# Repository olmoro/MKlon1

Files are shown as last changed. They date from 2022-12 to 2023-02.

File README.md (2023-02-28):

# <p align="center">MKlon1
# <p align="center">Вариант ЗУ с блоком управления на ESP32
## <p align="center">Модульное зарядное устройство на ESP-WROOM-32D
## <p align="center">проект Arduino.
#### <p align="right">редакция от 1 марта 2023 года 
#### <p align="right">Подключение ЖК-дисплея 3.5" 

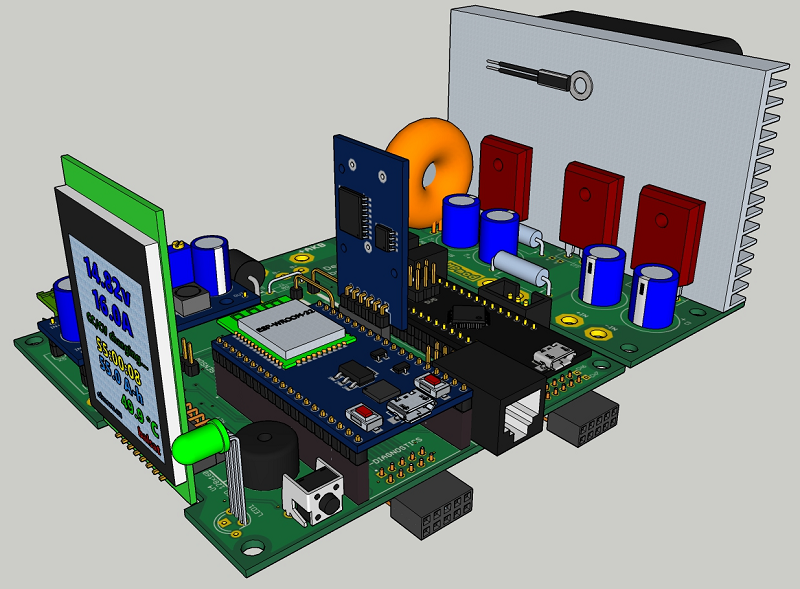
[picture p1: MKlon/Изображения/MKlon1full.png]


### MKlon1 - это вариант ЗУ, в котором блок управления и силовой  блок выполнены на отдельных платах. Что это дает?

Во-первых, блок управления - весьма универсальное устройство, применение которого не ограничивается зарядным устройством, чего не скажешь о силовом блоке, тем более, что силовой блок может "масштабироваться" - сегодня достаточно 6 ампер, а завтра ...

Во-вторых, платы имеют максимальный размер не более 102 мм, что позволяет заказывать их на [JLCPCB](https://jlcpcb.com/) по символической цене.

И, наконец, в случае неприятностей с силовым блоком более дорогой блок управления пострадает в меньшей степени.

Не стесняйтесь использовать код и технические решения в качестве отправной точки для вашего собственного проекта!

### <p align="center">Особенности реализации блока управления.

1. Модульность
  - Модуль [ESP32-DevKitC V4 38pin](https://aliexpress.ru/item/4000090521976.html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). Можно, конечно, ограничиться другими версиями ESP32-DevKit с уже распаяным ESP-WROOM-32D, но перспективнее будет запаять ESP32 с 16МБ памяти самостоятельно вместо обычных 4МБ. Выбор 38pin варианта ESP32-DevKitC вместо 30pin показался более подходящим при разработке топологии платы блока управления, не более того.
  - Модуль [SAMD21 M0-Mini](https://aliexpress.ru/item/4000169610268.html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). 
  - [Модуль прецизионных часов DS3231 IIC](https://aliexpress.ru/item/32822420722.html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). Опциональная позиция.
  - [Понижающий модуль LM2596](https://aliexpress.ru/item/32464248769.html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).
  - [Полноцветный ЖК-дисплей 1,8 дюйма 1,8x128 SPI TFT 160*128, модуль ST7735S](https://aliexpress.ru/item/1005003768467259.html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)
  - Или [ЖК-модуль HD 3,5 дюйма SPI, 480*320, TFT-модуль ILI9486 ILI9488, сенсорная панель, 65K цветов](https://sl.aliexpress.ru/p?key=ypWZtdN).  
  - [MIKROE-1892, I2C 1-Wire click DS2482-800 Development Kit for MikroBUS MIKROE-1892](https://www.chipdip.ru/product/mikroe-1892?ysclid=lc5odv6n7p797564389) может использоваться в вашем проекте для подключения до 8 датчиков температуры, но в этом проекте по конструктивным соображениям выбран вариант на DS2482-100 с сетевым подключением датчиков DS18B20 к единственному разъему на несущей плате.
2. Разъемы для установки модулей рекомендую не ставить те, что идут в комплекте, а использовать цанговые [разъемы](https://www.chipdip.ru/product0/8002610753), где это возможно.

3. Подключение модуля дисплея. Посадочное место на плате имеет два ряда по 8 контактов. Можно установить 8-контактный разъем для 1,8 дюймового дисплея или 14-контактный для 3,5-дюймового. В этом случае не устанавливаются RGB-светодиод и зуммер, так как портов ESP32 как бы много их не казалось, на всё не хватает.

4. Выходное напряжение модуля питания следует установить на 5,5 вольта. Потенциометр желательно заменить на подобранный резистор от греха подальше.

5. Два узла схемы нуждаются в гальванически развязанных [источниках питания](https://aliexpress.ru/item/1005003568781579.html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) на 5 и 12 вольт мощностью 1 ватт.

5. Токовые шунты могут устанавливаться как проволочные, так и металлопленочные SMD из расчета падения напряжения на шунте не более 200 милливольт при максимальном токе разряда (да и заряда тоже). 

6. Разъемы диагностики сигналов интерфейсов UART, SPI, IIC выведены на боковую сторону (если смотреть со стороны дисплея) двумя разъемами для подключения [логического анализатора](https://aliexpress.ru/item/1005004783286574.html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). На разъемы желательно нанести маркировку для правильного подключения логического анализатора. Впрочем, ему ничего не сделается при неправильном подключении.

7. Клавиатура пятикнопочная, подключается на разъем [6pin](https://aliexpress.ru/item/1005001530994945.html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). Резистивный делитель обеспечивает оптимальное напряжение на аналоговом входе микроконтроллера при нажатии одной кнопки. Подключение энкодера не предусмотрено.

8. Четырехточечное подключение к аккумуляторной батарее позволяет измерять напряжение на клеммах от -2 до 20 вольт и ток обоих направлений на одном шунте по дифференциальной схеме. Не любые ["крокодилы"](https://aliexpress.ru/item/4000593884517.html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) подойдут для этой цели, а только такие, с изолированными друг от друга "щечками". Для силовых проводов подойдет [12AWG](https://aliexpress.ru/item/32760772505.html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), для сигнальных - [26AWG](https://aliexpress.ru/item/32822800017.html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), скрепленных попарно термоусадкой c разумной дистанцией.

9. Охлаждение [радиатора](https://aliexpress.ru/item/1005003036398261.html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производится) 12-вольтовым вентилятором, напряжение должно регулироваться ШИМ. 

10. Мониторинг питания в пределах +20 вольт имеется.

11. Интерфейсы USB обоих процессорных модулей доступны без отключения модулей от несущей платы. Следует учесть, что у них разные "земли", и одновременное подключение к компьютеру не желательно, однако и не приводит к каким-либо печальным последствиям, разве что немного "уплывают" калибровки.

12. Кнопка сброса подключена к обоим процессорным модулям.

13. "Хитрый" 6-pin разъем с закороченными контактами в линии связи управляющего модуля ESP32 с измерительным SAMD21 по асинхронному интерфейсу можно не устанавливать. Однако если возникает необходимость по отдельности управлять каждым модулем в процессе разработки, то он понадобится, а проводники перерезать. Потом использовать джамперы.

14. На силовом модуле размещена лишь символическая нагрузка цепи разряда, необходимая для поддержания устойчивой работы преобразователя в некоторых режимах. Для разряда током заявленной величины клеммы "LOAD" должны быть закорочены или к ним подключена внешняя нагрузка в разумных пределах.

15. Код предлагается портировать из проектов MKlon2 и MDrv2 самостоятельно.

16. Если вы думаете, что я что-то пропустил или что-то не так, пожалуйста, дайте мне знать: molvas66 на mail.ru

17. И, наконец, видео без звука и титров [95M скачать](https://github.com/olmoro/MKlon1/blob/main/MKlon/%D0%92%D0%B8%D0%B4%D0%B5%D0%BE/MKlon1.mp4?raw=true)

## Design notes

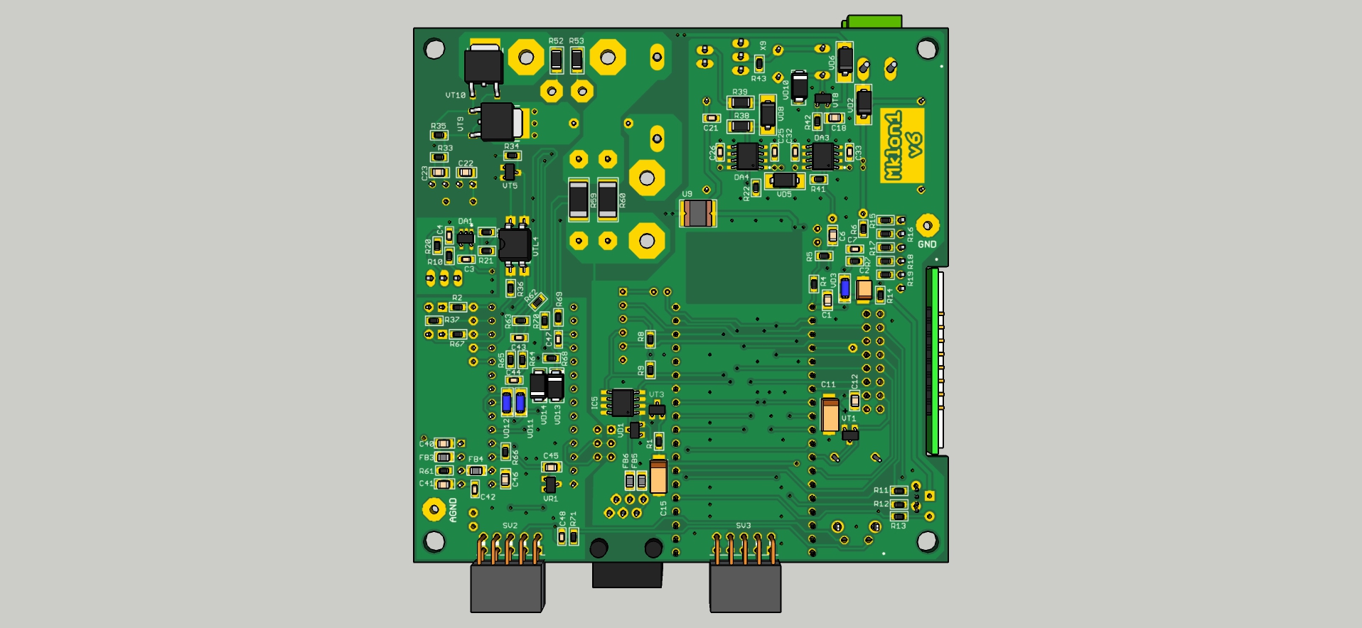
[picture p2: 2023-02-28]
Модуль управления/Изображения/MKlon1v6_bot.jpg

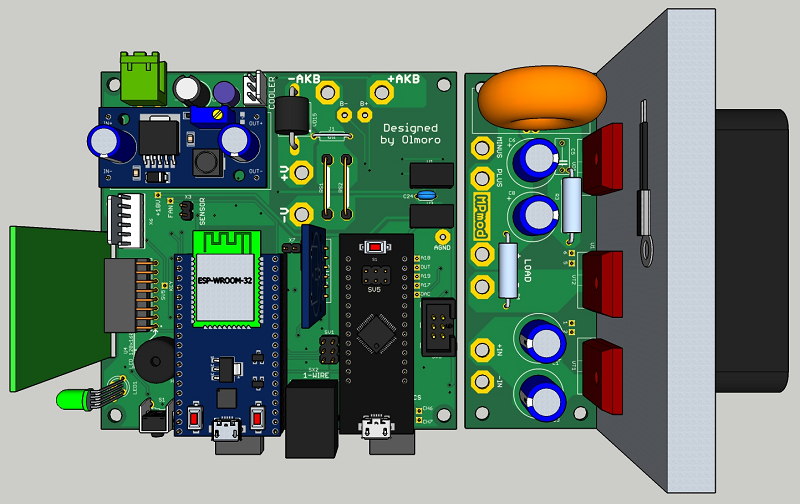
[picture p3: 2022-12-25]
MKlon/Изображения/MKlon1full_top.png

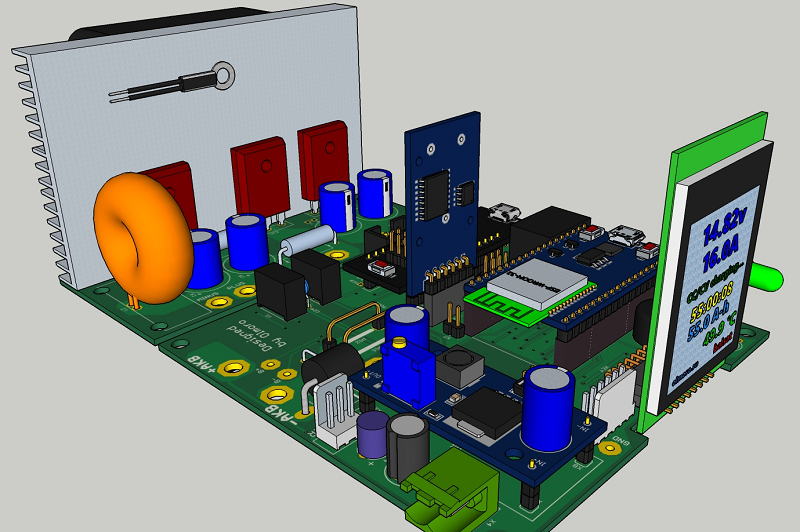
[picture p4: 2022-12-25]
MKlon/Изображения/MKlon1full2.png

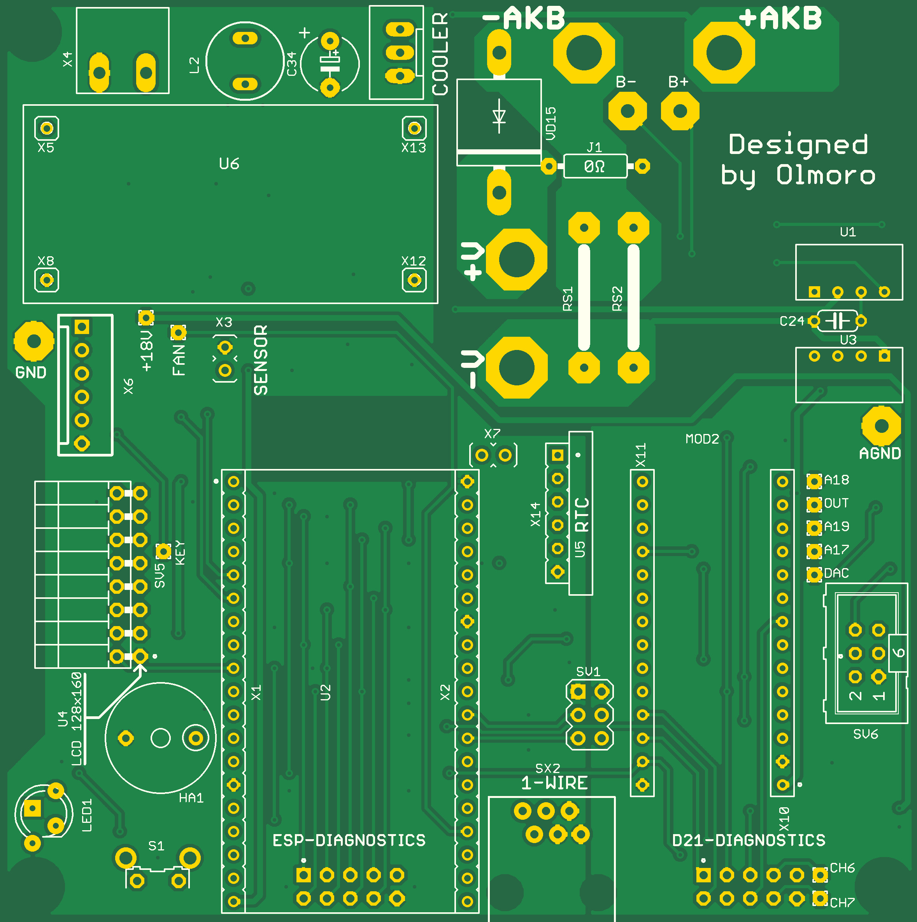
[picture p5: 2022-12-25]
Модуль управления/Изображения/eagleUp_Mklon1v3_board_top.jpg

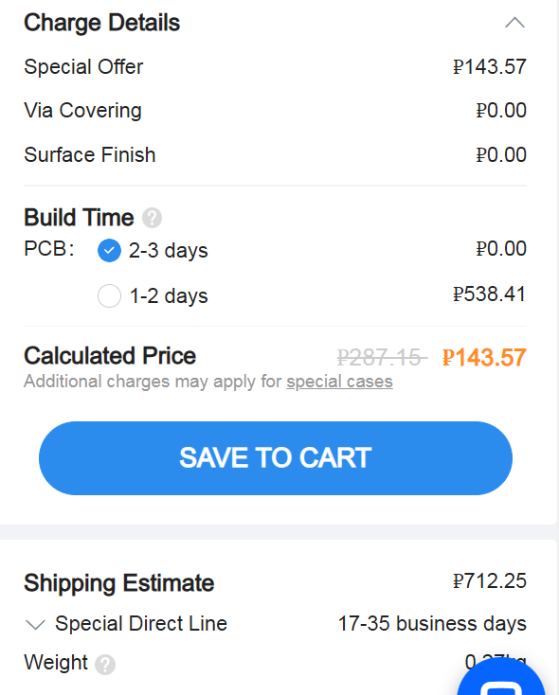
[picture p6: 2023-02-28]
Модуль управления/Gerber/price.png

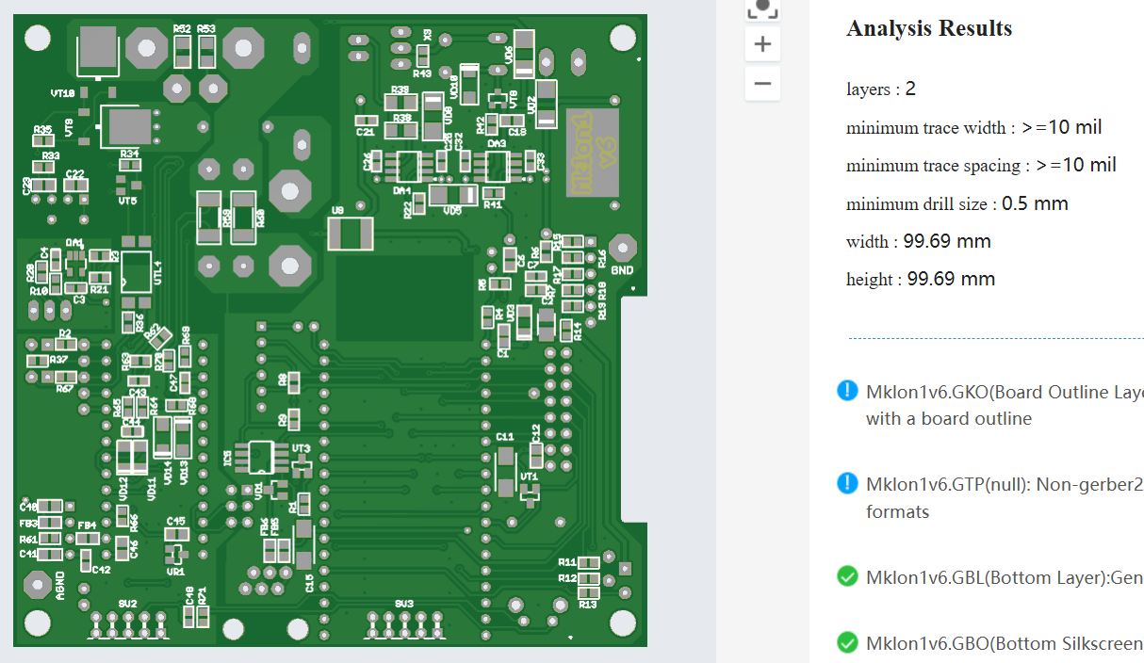
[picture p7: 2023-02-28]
Модуль управления/Gerber/bottom.png

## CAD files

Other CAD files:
Силовой модуль/Модели/MPmod.skp

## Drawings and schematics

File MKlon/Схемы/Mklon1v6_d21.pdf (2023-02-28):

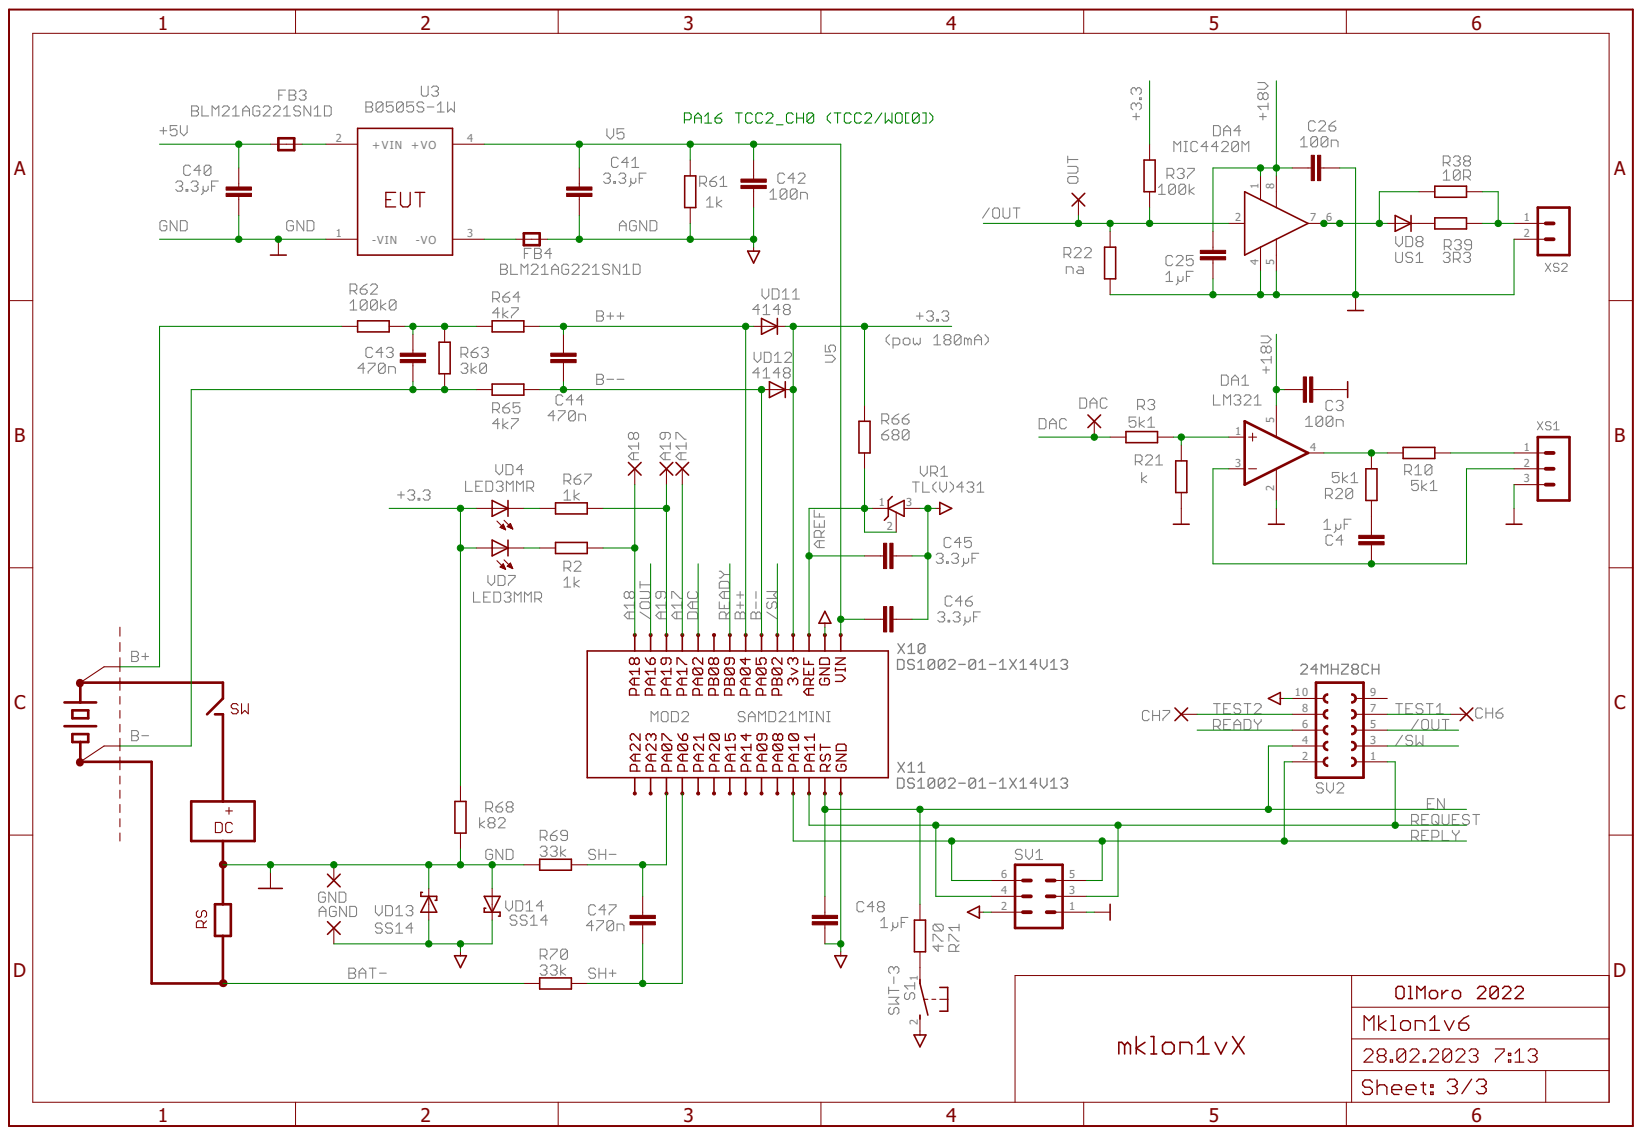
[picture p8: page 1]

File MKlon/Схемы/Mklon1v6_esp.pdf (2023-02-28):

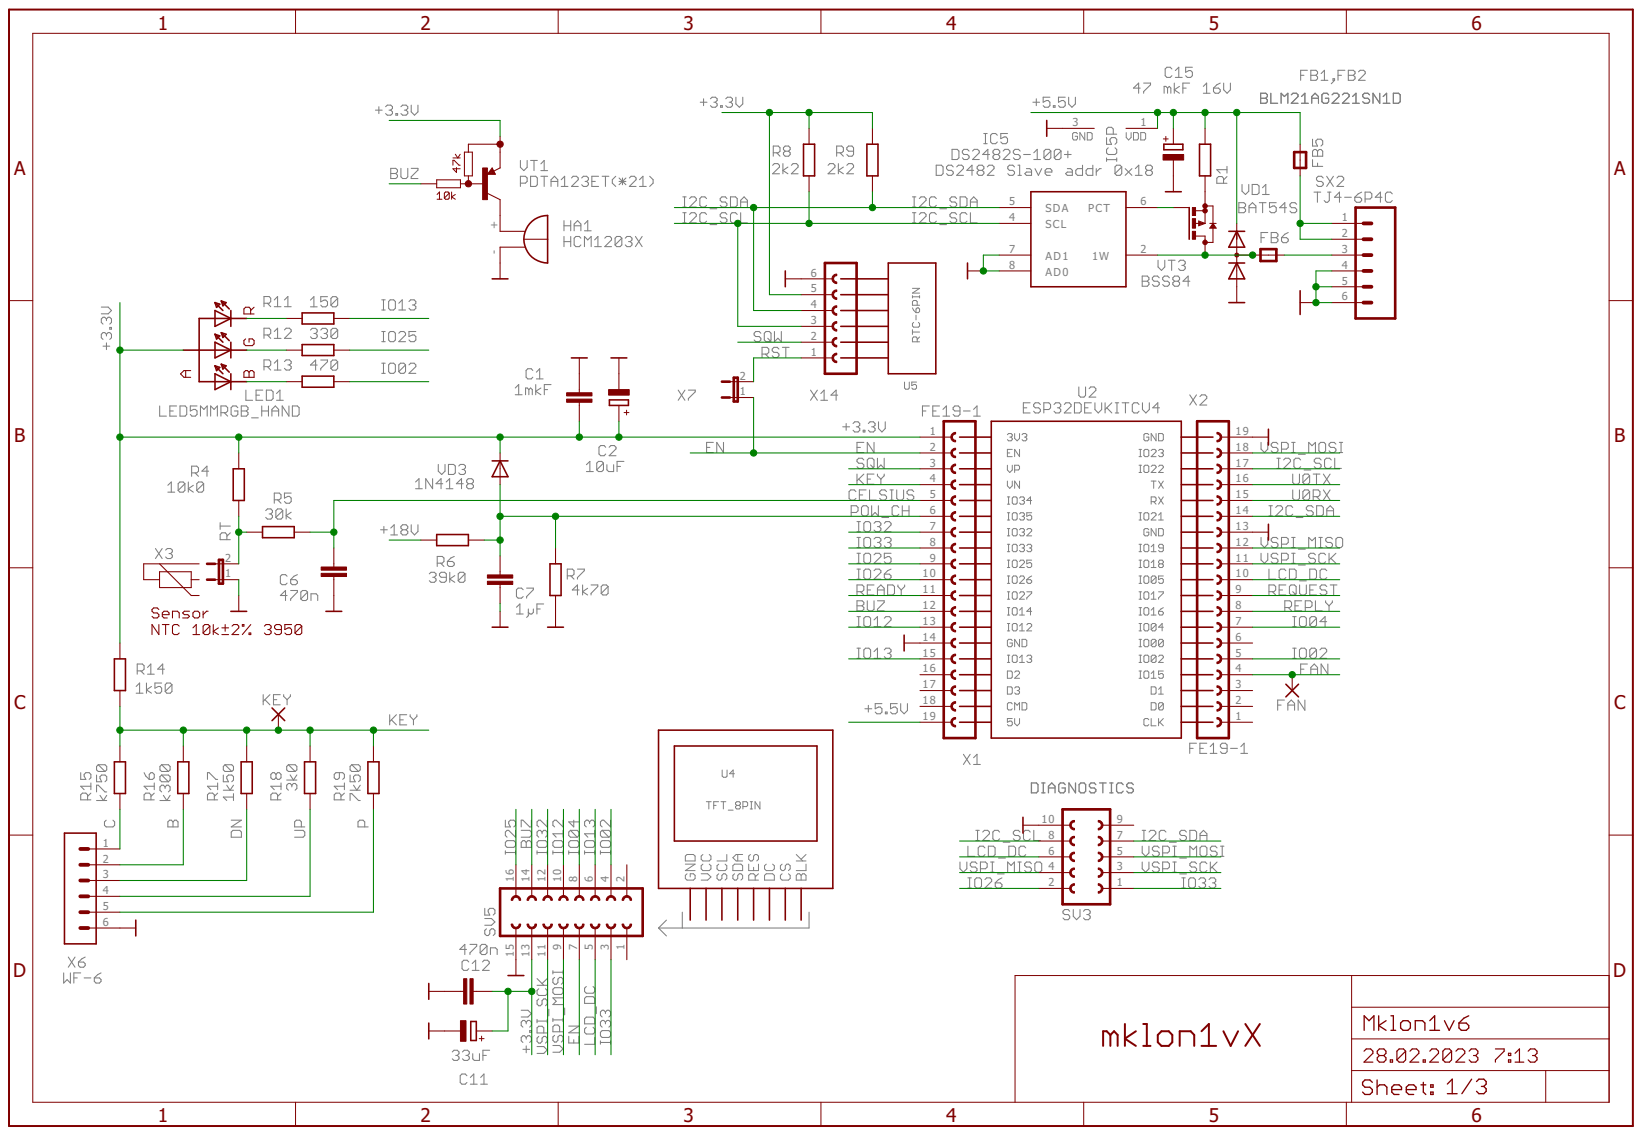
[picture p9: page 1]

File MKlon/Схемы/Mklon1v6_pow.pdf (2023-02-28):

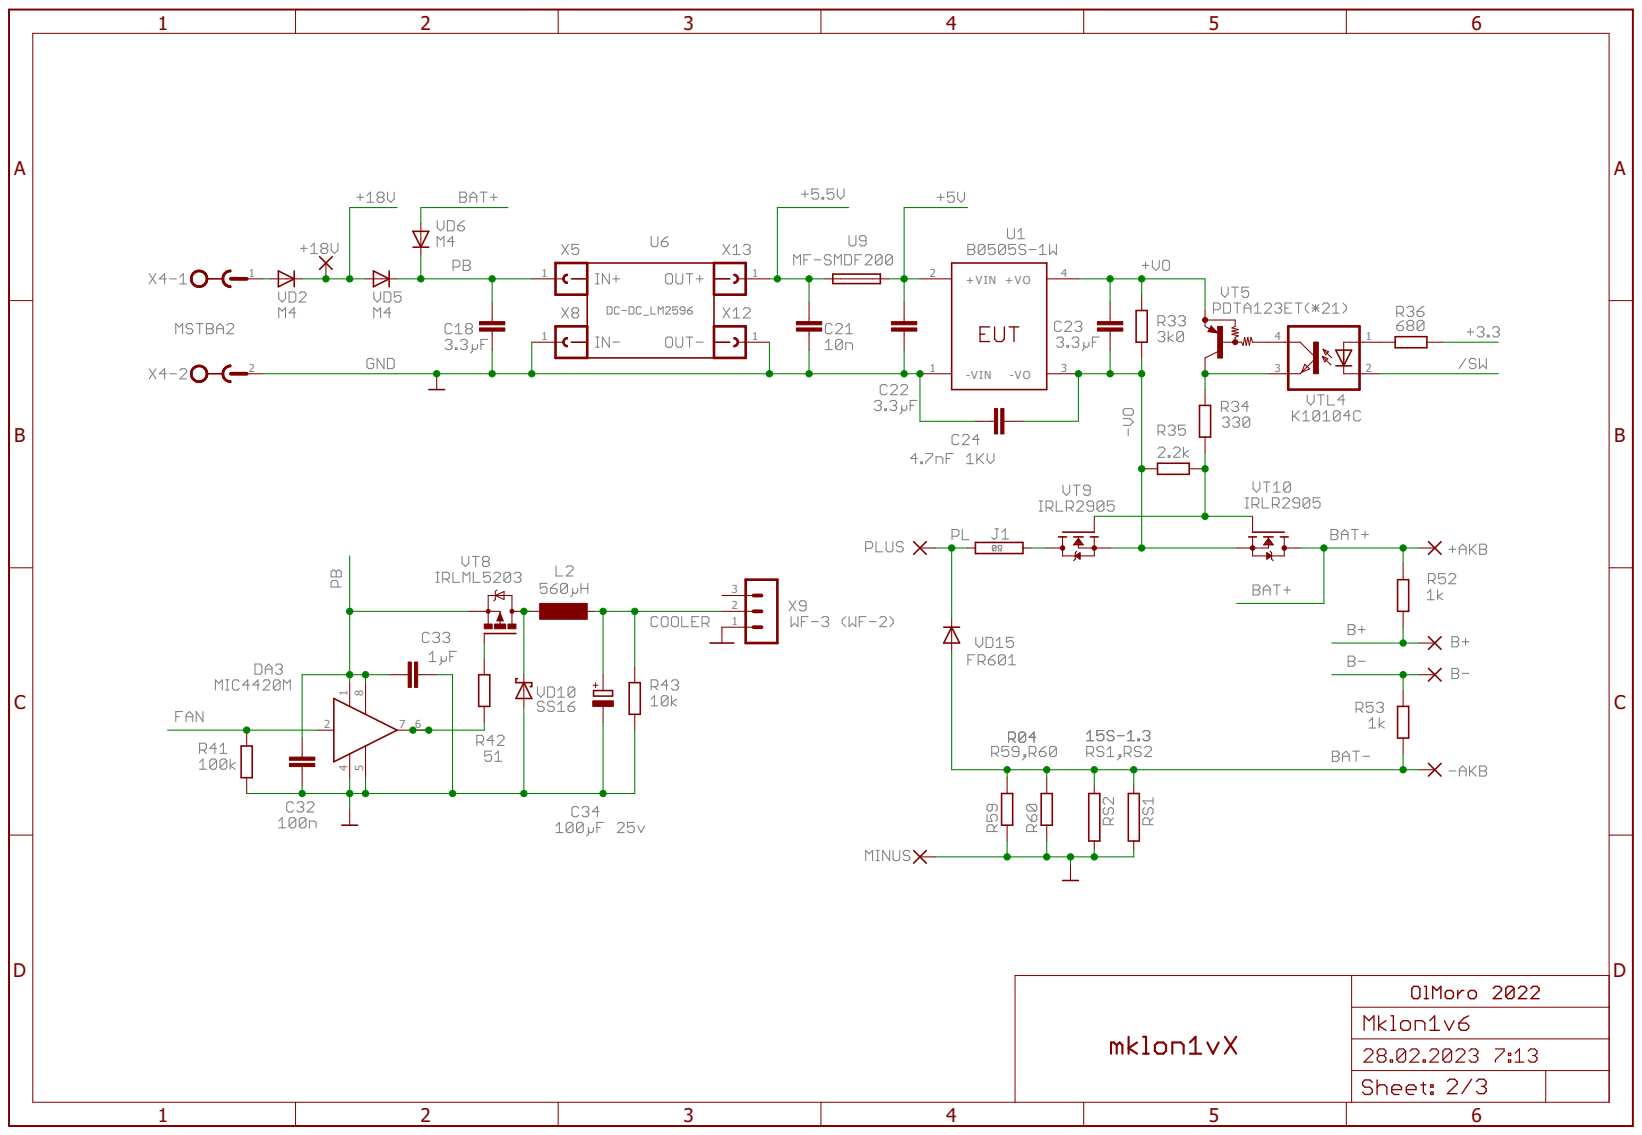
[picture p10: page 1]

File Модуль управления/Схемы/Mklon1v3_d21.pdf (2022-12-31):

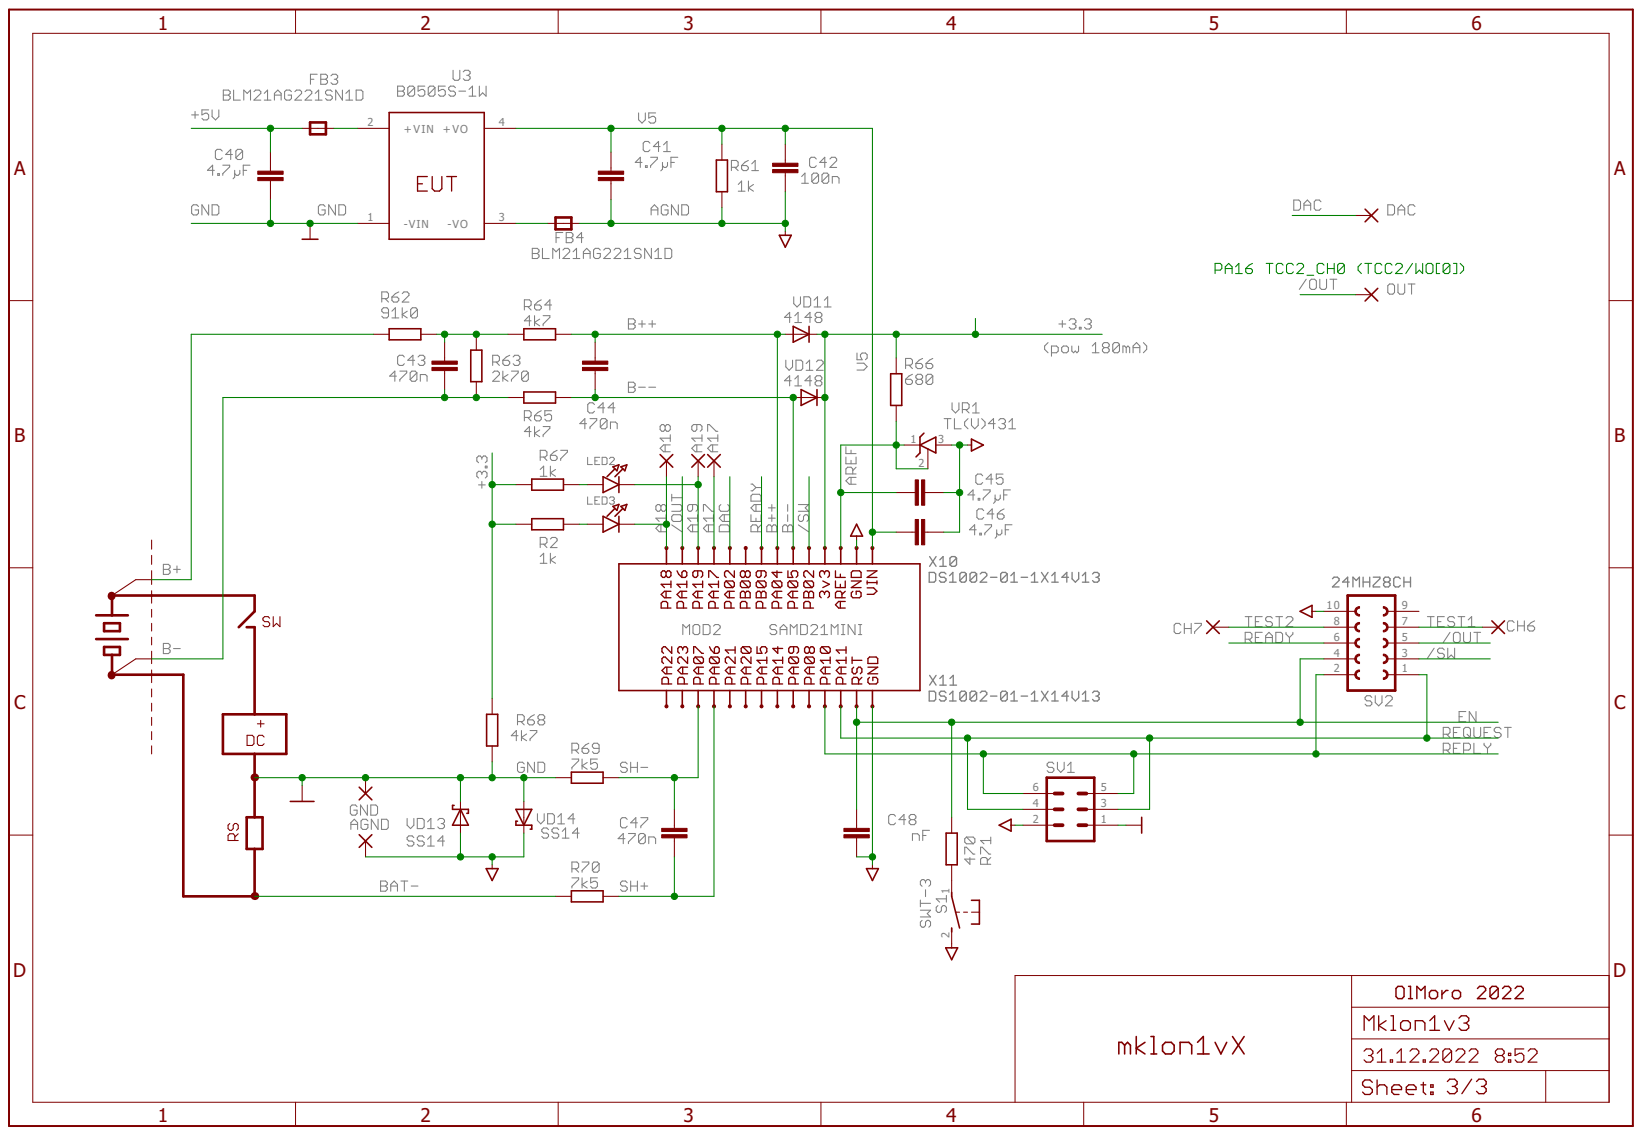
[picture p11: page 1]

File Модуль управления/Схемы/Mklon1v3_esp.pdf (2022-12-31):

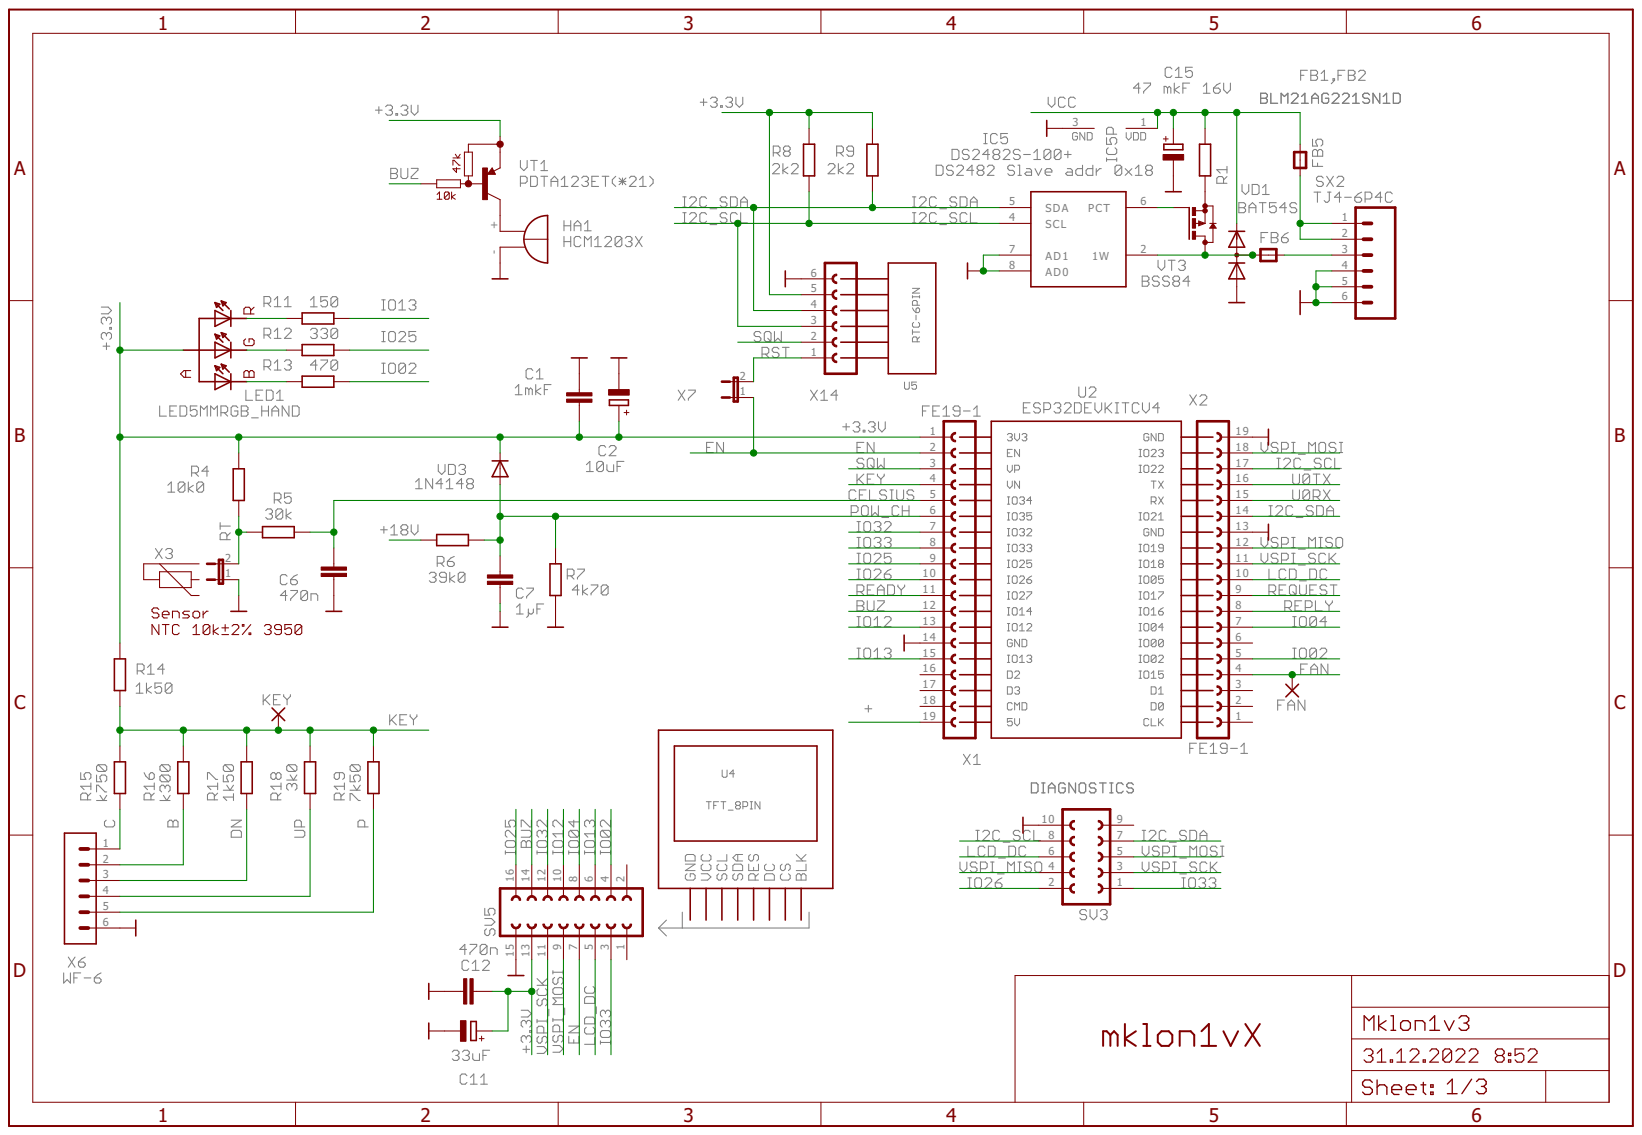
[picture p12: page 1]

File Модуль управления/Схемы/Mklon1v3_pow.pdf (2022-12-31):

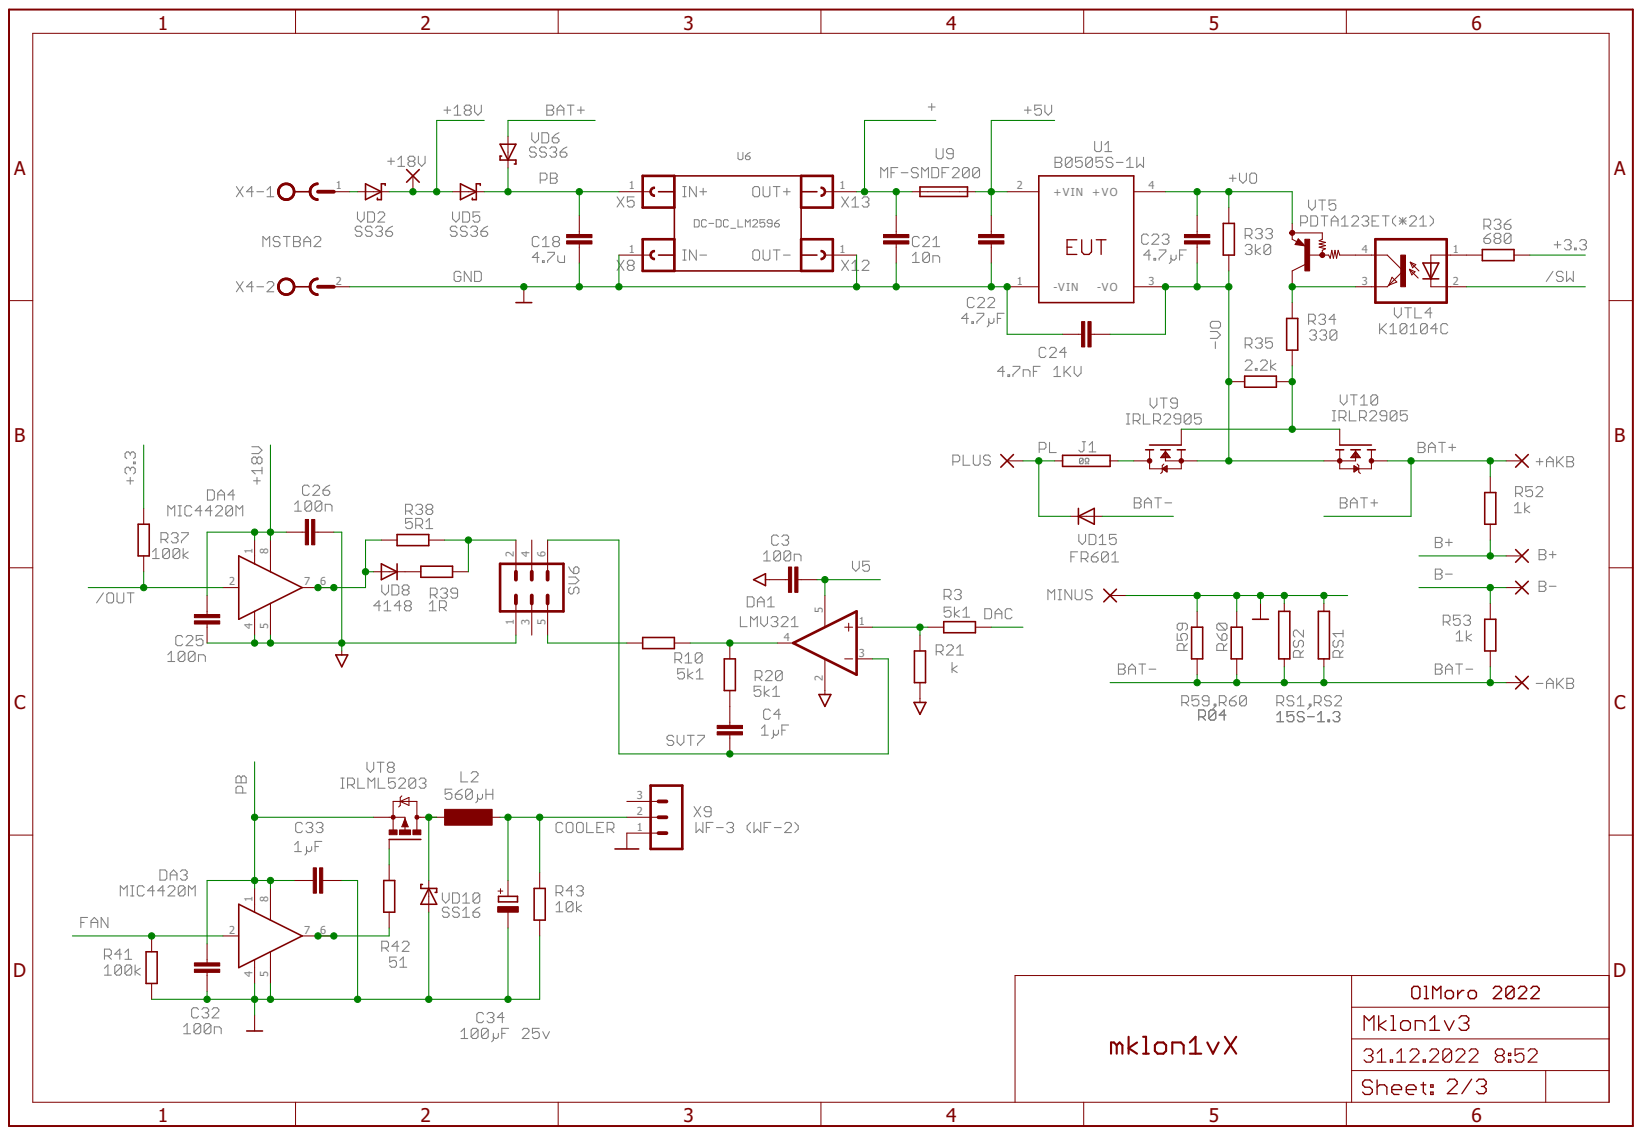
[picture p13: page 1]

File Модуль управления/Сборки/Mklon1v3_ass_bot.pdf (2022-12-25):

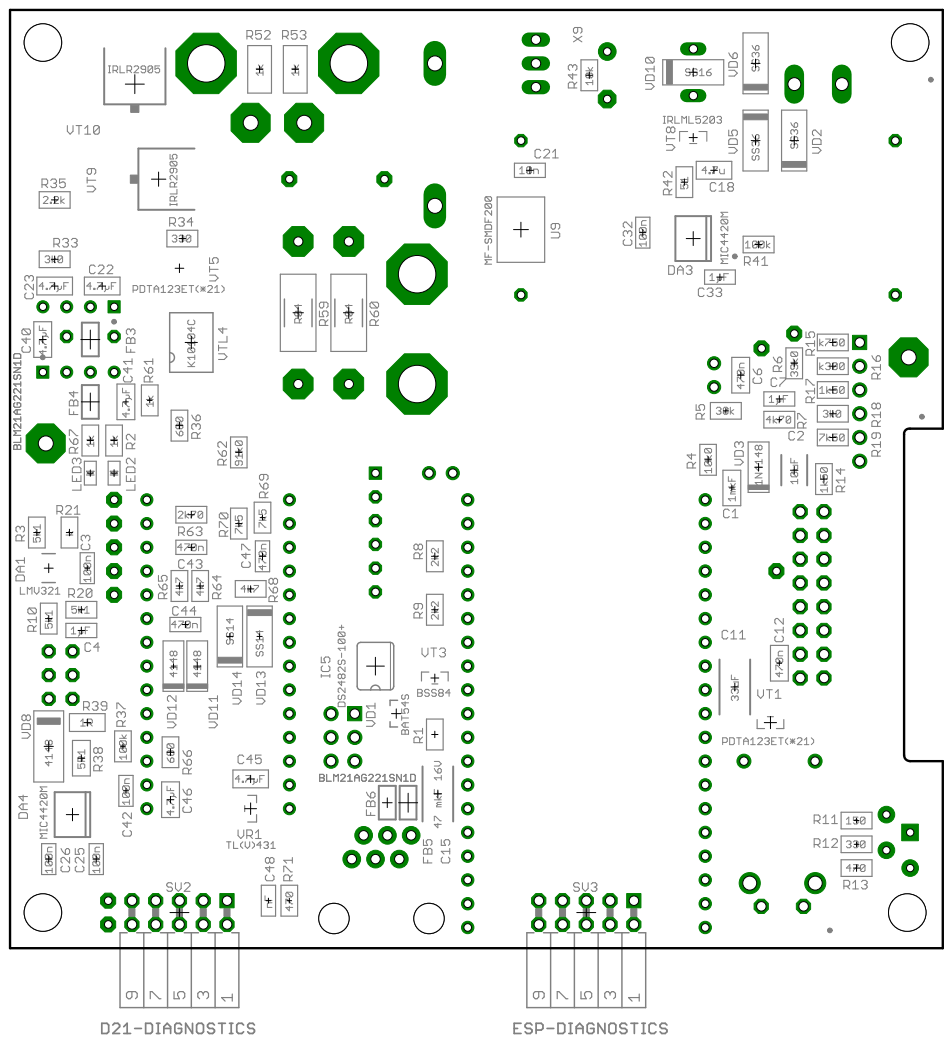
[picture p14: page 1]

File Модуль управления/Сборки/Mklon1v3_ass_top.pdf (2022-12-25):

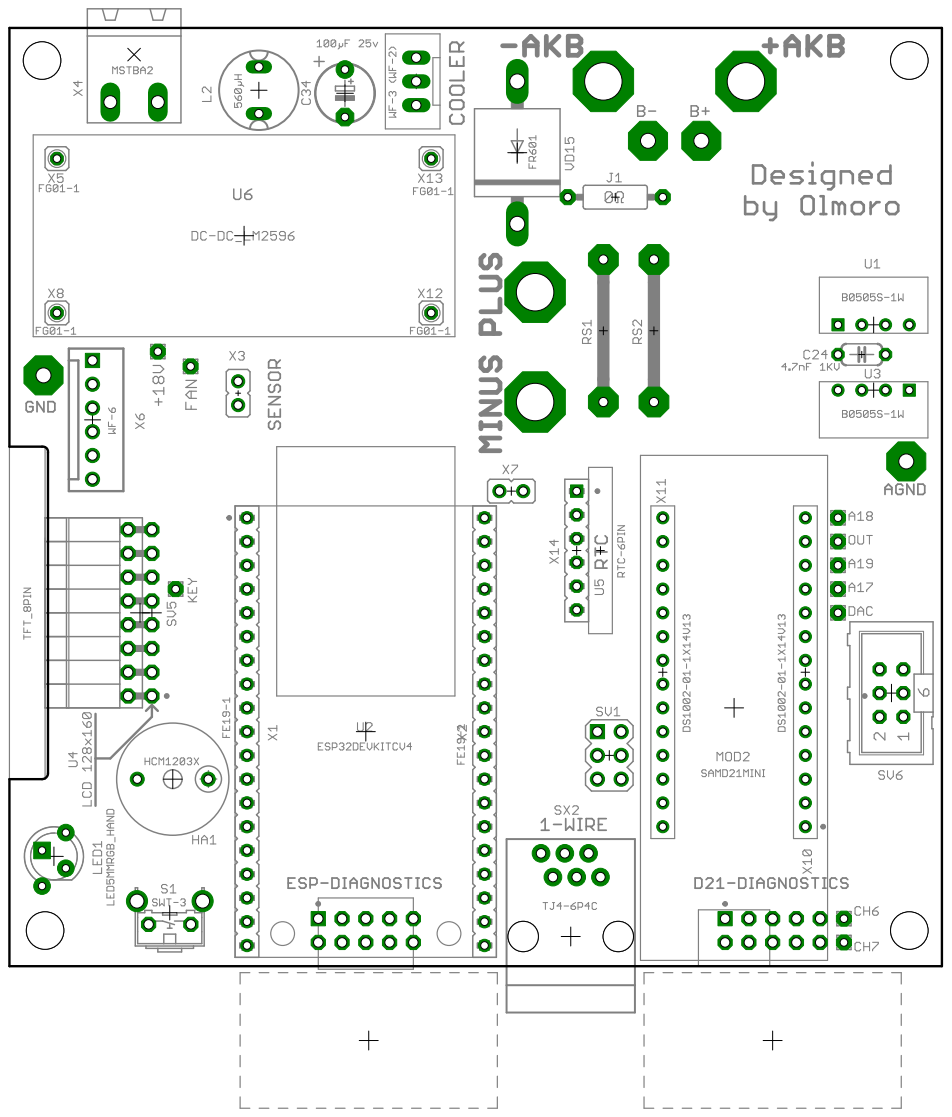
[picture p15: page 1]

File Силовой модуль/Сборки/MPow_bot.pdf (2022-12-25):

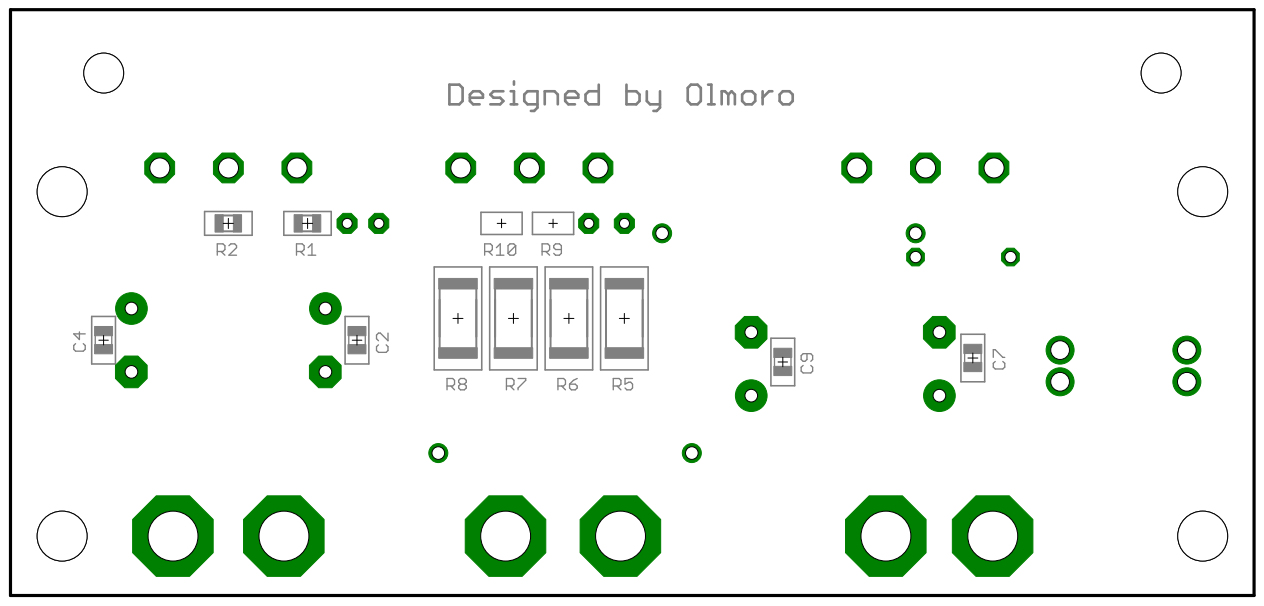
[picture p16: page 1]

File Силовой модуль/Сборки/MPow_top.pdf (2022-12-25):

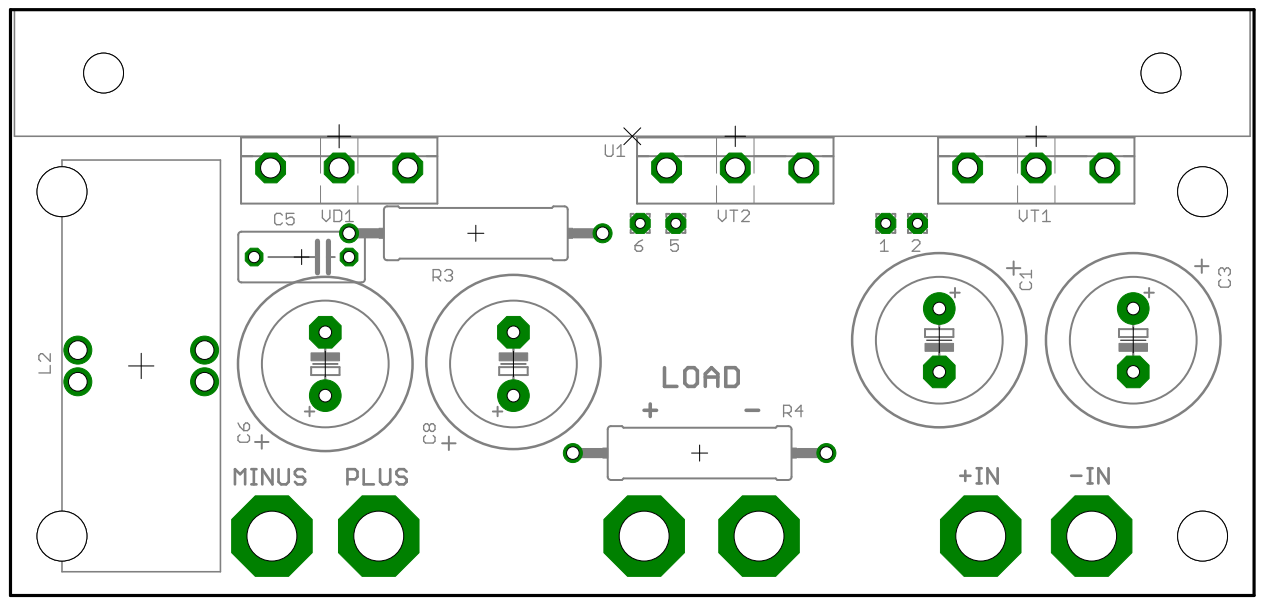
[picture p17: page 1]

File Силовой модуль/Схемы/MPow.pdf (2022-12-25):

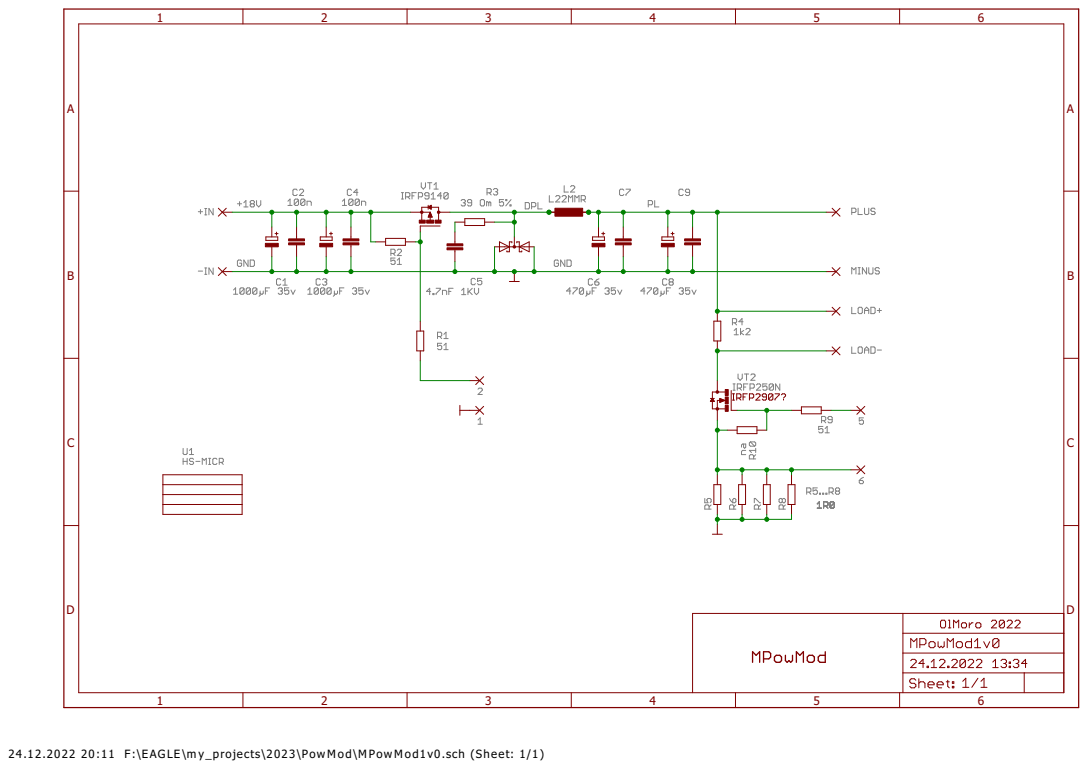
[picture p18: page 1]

24.12.2022 20:11 F:\EAGLE\my_projects\2023\PowMod\MPowMod1v0.sch (Sheet: 1/1)
